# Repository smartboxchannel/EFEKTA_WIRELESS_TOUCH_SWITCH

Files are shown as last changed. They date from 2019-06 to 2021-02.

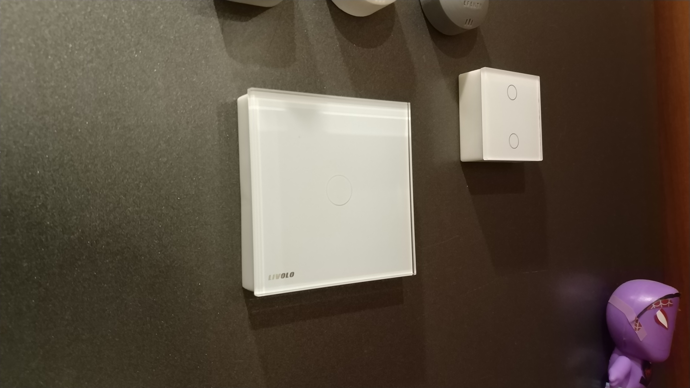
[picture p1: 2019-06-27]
IMAGES/IMG_20190627_012042.jpg

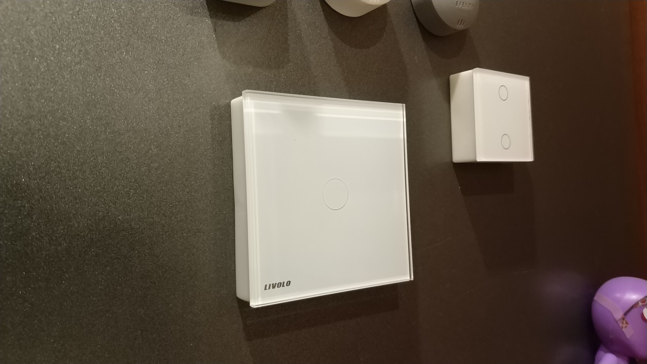
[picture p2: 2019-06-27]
IMAGES/IMG_20190627_012049.jpg

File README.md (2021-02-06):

Wireless Touch Switch sensor based on nRF52832 with fluorescent effect. Running on cr2450 battery (550mA).

Use the MySensors library

#### Don't donate to me, it doesn't work in this world: https://paypal.me/efektalab , just buy:

More info at http://efektalab.com/wts52

Contact: hello@efektalab.com

---

---

Components (see also BOM.CSV):

Luxury Crystal White Glass Touch Switch Panel 80mm*80mm - http://ali.ski/s-sSY

Luminous Tape Night Vision Glow - http://ali.ski/LCVzK

ANYCUBIC 405nm UV Resin For Photon 3D Printer - http://ali.ski/MQ5yO3

Head Micro Screws Round - http://ali.ski/Tqzrc

Super Strong Block Square Rare Earth Neodymium Magnets - http://ali.ski/Edmjy

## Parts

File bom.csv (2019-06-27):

Qty | Value | Device | Package | Parts | Description | MF | MPN | Aliexpress or Ebay link
2 | 100nF | 50v | +80-20% |  | SMD 0805 | C1, C4 | SMD ceramic capacitor 100nF | Y5V |  |  | http://ali.ski/nnISH
1 | 47uF | 6v3 | 10% |  | SMD 1812 | C2 | SMD ceramic capacitor 47uF | Y5V |  |  | http://ali.ski/B89nD8
1 | 10pF | 50v | +80-20% |  | SMD 0805 | C3 | SMD ceramic capacitor 47uF | Y5V (optional) |  |  | http://ali.ski/nnISH
2 | 10K | 5% |  | SMD 0805 | R1, R2 | SMD resistor 10K Ohm |  |  | http://ali.ski/x9ghl
1 | 100K | 5% |  | SMD 0805 | R3 | SMD resistor 100K Ohm |  |  | http://ali.ski/x9ghl
2 | 2K | 5% |  | SMD 0805 | R4, R6 | SMD resistor 2K Ohm |  |  | http://ali.ski/x9ghl
1 | 360 | 5% |  | SMD 0805 | R5 | SMD resistor 360 Ohm |  |  | http://ali.ski/x9ghl
2 | 1PS76SB10.115 |  | SOD-323 | D1, D2 | SMD Schottky Barrier Diode |  |  | http://ali.ski/5dTu7U
1 | 2x3P | 6pin | 1.27mm |  | SMT | J1 | Pin Header Female |  |  | http://ali.ski/tKqX1J
1 | RGB LED |  | SMD 0805 | RGBL1 | RGB LED |  |  | http://ali.ski/BPc4y
1 | YJ-17103 |  | SMT | U2 | nRF52832 Module |  |  | http://ali.ski/elwkT
2 | Button |  | SMT | U3, U4 | b4.5x4.5 |  |  | http://ali.ski/7eX0DK
1 | TTP223 |  | SOT-23-6L | U5 | 1 KEY TOUCH PAD DETECTOR IC |  |  | http://ali.ski/RrWnC
1 | HU-2450 N-1 |  | DIP | U6 | Battery Holder |  |  | https://ru.mouser.com/ProductDetail/Renata/HU2450N-1?qs=weLdYPLz6SNVHVWWurrMmw%3D%3D

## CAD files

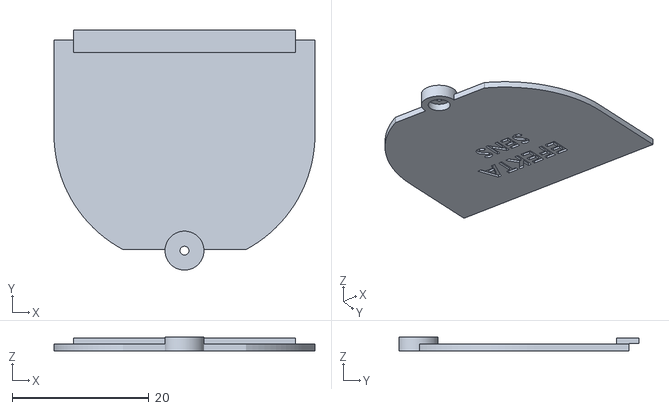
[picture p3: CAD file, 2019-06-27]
CASE/2.STL
38.2 x 35.2 x 2.00

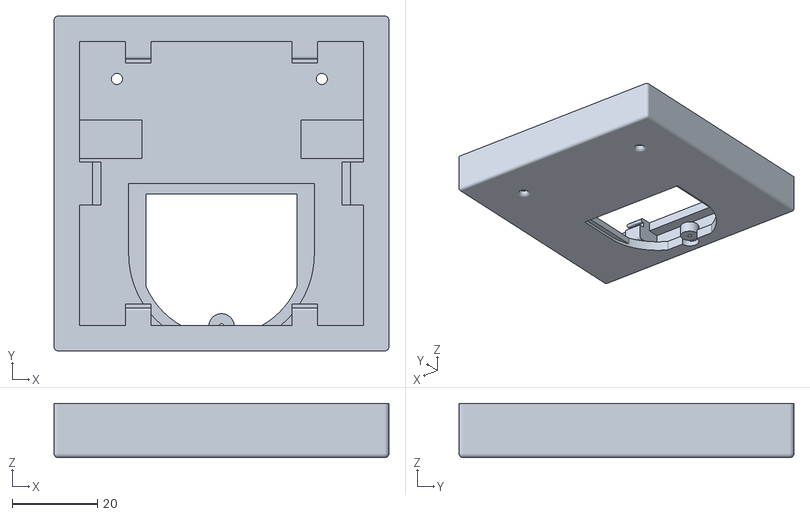
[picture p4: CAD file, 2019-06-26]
CASE/1.STL
78.5 x 78.5 x 12.7

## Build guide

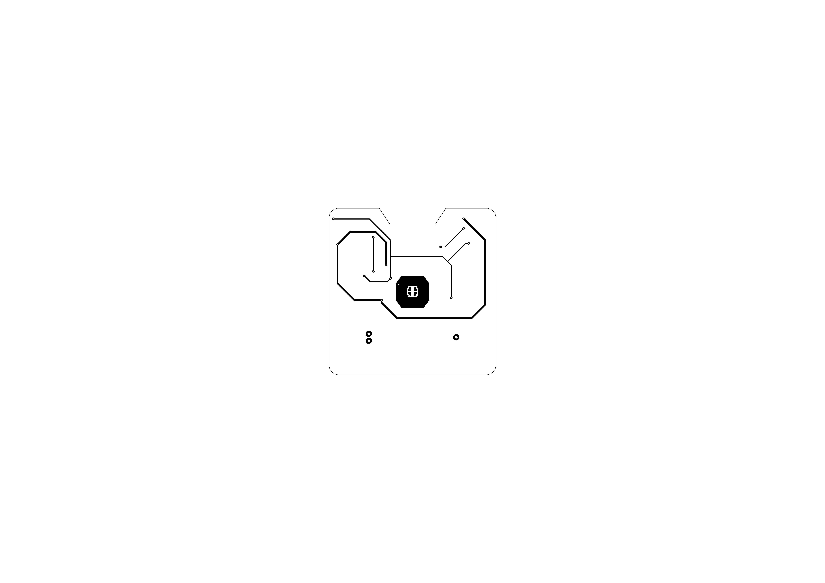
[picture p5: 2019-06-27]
GERBER_FILES/LUT_HAND_MADE/PRINT/1.jpg

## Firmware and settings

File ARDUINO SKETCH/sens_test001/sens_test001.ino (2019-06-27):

/**
  ТЕСТОВЫЙ СКЕТЧ СЕНСОРНОГО ВЫКЛЮЧАТЕЛЯ С ПРЕРЫВАНИЯМИ НА NRF_LPCOMP
*/
bool button_flag;
bool sens_flag;
bool send_flag;
bool detection;
bool nosleep;
byte timer;
unsigned long SLEEP_TIME = 21600000; //6 hours
unsigned long oldmillis;
unsigned long newmillis;
unsigned long interrupt_time;
unsigned long SLEEP_TIME_W;
uint16_t currentBatteryPercent;
uint16_t batteryVoltage = 0;
uint16_t battery_vcc_min = 2400;
uint16_t battery_vcc_max = 3000;

#define MY_RADIO_NRF5_ESB
//#define MY_PASSIVE_NODE
#define MY_NODE_ID 30
#define MY_PARENT_NODE_ID 0
#define MY_PARENT_NODE_IS_STATIC
#define MY_TRANSPORT_UPLINK_CHECK_DISABLED
#define IRT_PIN 3 //(PORT0,  gpio 5)
#include <MySensors.h>
// see https://www.mysensors.org/download/serial_api_20
#define SENS_CHILD_ID 0
#define CHILD_ID_VOLT 254
MyMessage sensMsg(SENS_CHILD_ID, V_VAR1);
//MyMessage voltMsg(CHILD_ID_VOLT, V_VOLTAGE);


void preHwInit() {
  sleep(2000);
  pinMode(RED_LED, OUTPUT);
  digitalWrite(RED_LED, HIGH);
  pinMode(GREEN_LED, OUTPUT);
  digitalWrite(GREEN_LED, HIGH);
  pinMode(BLUE_LED, OUTPUT);
  digitalWrite(BLUE_LED, HIGH);
  pinMode(MODE_PIN, INPUT);
  pinMode(SENS_PIN, INPUT);
}

void before()
{
  NRF_POWER->DCDCEN = 1;
  NRF_UART0->ENABLE = 0;
  sleep(1000);
  digitalWrite(BLUE_LED, LOW);
  sleep(150);
  digitalWrite(BLUE_LED, HIGH);
}

void presentation()  {
  sendSketchInfo("EFEKTA Sens 1CH Sensor", "1.1");
  present(SENS_CHILD_ID, S_CUSTOM, "SWITCH STATUS");
  //present(CHILD_ID_VOLT, S_MULTIMETER, "Battery");
}

void setup() {
  digitalWrite(BLUE_LED, LOW);
  sleep(100);
  digitalWrite(BLUE_LED, HIGH);
  sleep(200);
  digitalWrite(BLUE_LED, LOW);
  sleep(100);
  digitalWrite(BLUE_LED, HIGH);
  lpComp();
  detection = false;
  SLEEP_TIME_W = SLEEP_TIME;
  pinMode(31, OUTPUT);
  digitalWrite(31, HIGH);
  /*
    while (timer < 10) {
    timer++;
    digitalWrite(GREEN_LED, LOW);
    wait(5);
    digitalWrite(GREEN_LED, HIGH);
    wait(500);
    }
    timer = 0;
  */
  sleep(7000);
  while (timer < 3) {
    timer++;
    digitalWrite(GREEN_LED, LOW);
    sleep(15);
    digitalWrite(GREEN_LED, HIGH);
    sleep(85);
  }
  timer = 0;
  sleep(1000);
}

void loop() {

  if (detection) {
    if (digitalRead(MODE_PIN) == 1 && button_flag == 0 && digitalRead(SENS_PIN) == 0) {
      //back side button detection
      button_flag = 1;
      nosleep = 1;
    }
    if (digitalRead(MODE_PIN) == 1 && button_flag == 1 && digitalRead(SENS_PIN) == 0) {
      digitalWrite(RED_LED, LOW);
      wait(10);
      digitalWrite(RED_LED, HIGH);
      wait(50);
    }
    if (digitalRead(MODE_PIN) == 0 && button_flag == 1 && digitalRead(SENS_PIN) == 0) {
      nosleep = 0;
      button_flag = 0;
      digitalWrite(RED_LED, HIGH);
      lpComp_reset();
    }

    if (digitalRead(SENS_PIN) == 1 && sens_flag == 0 && digitalRead(MODE_PIN) == 0) {
      //sens detection
      sens_flag = 1;
      nosleep = 1;
      newmillis = millis();
      interrupt_time = newmillis - oldmillis;
      SLEEP_TIME_W = SLEEP_TIME_W - interrupt_time;
      if (send(sensMsg.set(detection))) {
        send_flag = 1;
      }
    }
    if (digitalRead(SENS_PIN) == 1 && sens_flag == 1 && digitalRead(MODE_PIN) == 0) {
      if (send_flag == 1) {
        while (timer < 10) {
          timer++;
          digitalWrite(GREEN_LED, LOW);
          wait(20);
          digitalWrite(GREEN_LED, HIGH);
          wait(30);
        }
        timer = 0;
      } else {
        while (timer < 10) {
          timer++;
          digitalWrite(RED_LED, LOW);
          wait(20);
          digitalWrite(RED_LED, HIGH);
          wait(30);
        }
        timer = 0;
      }
    }
    if (digitalRead(SENS_PIN) == 0 && sens_flag == 1 && digitalRead(MODE_PIN) == 0) {
      sens_flag = 0;
      nosleep = 0;
      send_flag = 0;
      digitalWrite(GREEN_LED, HIGH);
      sleep(500);
      lpComp_reset();
    }
    if (SLEEP_TIME_W < 60000) {
      SLEEP_TIME_W = SLEEP_TIME;
      sendBatteryStatus();
    }
  }
  else {
    //if (detection == -1) {
    SLEEP_TIME_W = SLEEP_TIME;
    sendBatteryStatus();
  }
  if (nosleep == 0) {
    oldmillis = millis();
    sleep(SLEEP_TIME_W);
  }
}

void sendBatteryStatus() {
  wait(20);
  batteryVoltage = hwCPUVoltage();
  wait(2);

  if (batteryVoltage > battery_vcc_max) {
    currentBatteryPercent = 100;
  }
  else if (batteryVoltage < battery_vcc_min) {
    currentBatteryPercent = 0;
  } else {
    currentBatteryPercent = (100 * (batteryVoltage - battery_vcc_min)) / (battery_vcc_max - battery_vcc_min);
  }

  sendBatteryLevel(currentBatteryPercent, 1);
  wait(2000, C_INTERNAL, I_BATTERY_LEVEL);
  //send(powerMsg.set(batteryVoltage), 1);
  //wait(2000, 1, V_VAR1);
}

void lpComp() {
  NRF_LPCOMP->PSEL = IRT_PIN;
  NRF_LPCOMP->ANADETECT = 1;
  NRF_LPCOMP->INTENSET = B0100;
  NRF_LPCOMP->ENABLE = 1;
  NRF_LPCOMP->TASKS_START = 1;
  NVIC_SetPriority(LPCOMP_IRQn, 15);
  NVIC_ClearPendingIRQ(LPCOMP_IRQn);
  NVIC_EnableIRQ(LPCOMP_IRQn);
}

void s_lpComp() {
  if ((NRF_LPCOMP->ENABLE) && (NRF_LPCOMP->EVENTS_READY)) {
    NRF_LPCOMP->INTENCLR = B0100;
  }
}

void r_lpComp() {
  NRF_LPCOMP->INTENSET = B0100;
}

#if __CORTEX_M == 0x04
#define NRF5_RESET_EVENT(event)                                                 \
  event = 0;                                                                   \
  (void)event
#else
#define NRF5_RESET_EVENT(event) event = 0
#endif

extern "C" {
  void LPCOMP_IRQHandler(void) {
    detection = true;
    NRF5_RESET_EVENT(NRF_LPCOMP->EVENTS_UP);
    NRF_LPCOMP->EVENTS_UP = 0;
    MY_HW_RTC->CC[0] = (MY_HW_RTC->COUNTER + 2);
  }
}

void lpComp_reset () {
  s_lpComp();
  detection = false;
  NRF_LPCOMP->EVENTS_UP = 0;
  r_lpComp();
}

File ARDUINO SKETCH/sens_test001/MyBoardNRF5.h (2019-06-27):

/*
  If you don't use an nRF5 board, you can ignore this file.

  This file was part of the "My Sensors nRF5 Boards" board repository
  available at https://github.com/mysensors/ArduinoBoards If you have
  questions, please refer the documentation at
  https://github.com/mysensors/ArduinoHwNRF5 first.

  This file is compatible with ArduinoHwNRF5 >= 0.2.0

  This file allows you to change the pins of internal hardware, like the
  serial port, SPI bus or Wire bus.

  All pins referenced here are mapped via the "g_ADigitalPinMap" Array
  defined in "MyBoardNRF5.cpp" to pins of the MCU.
  
  As an example, if you have at the third position in "g_ADigitalPinMap" the
  12, then all ports referenced in Arduino with 2 are mapped to P0.12. If you
  don't change the "g_ADigitalPinMap" Array, the Arduino pins 0..31 are
  translated to P0.00..P0..31.
   
  ###########################################################################
 
  This file is compatible with ArduinoHwNRF5 > 0.1.0
  Copyright (c) 2014-2015 Arduino LLC.  All right reserved.
  Copyright (c) 2016 Sandeep Mistry. All right reserved.
  Copyright (c) 2017 Sensnology AB. All right reserved.

  This library is free software; you can redistribute it and/or
  modify it under the terms of the GNU Lesser General Public
  License as published by the Free Software Foundation; either
  version 2.1 of the License, or (at your option) any later version.
  This library is distributed in the hope that it will be useful,
  but WITHOUT ANY WARRANTY; without even the implied warranty of
  MERCHANTABILITY or FITNESS FOR A PARTICULAR PURPOSE.
  See the GNU Lesser General Public License for more details.
  You should have received a copy of the GNU Lesser General Public
  License along with this library; if not, write to the Free Software
  Foundation, Inc., 51 Franklin St, Fifth Floor, Boston, MA  02110-1301  USA
*/

#ifndef _MYBOARDNRF5_H_
#define _MYBOARDNRF5_H_

#ifdef __cplusplus
extern "C"
{
#endif // __cplusplus

// Number of pins defined in PinDescription array
#define PINS_COUNT           (32u)
#define NUM_DIGITAL_PINS     (32u)
#define NUM_ANALOG_INPUTS    (8u)
#define NUM_ANALOG_OUTPUTS   (8u)

/* 
 *  LEDs
 *  
 *  This is optional
 *  
 *  With My Sensors, you can use
 *  hwPinMode() instead of pinMode()
 *  hwPinMode() allows to use advanced modes like OUTPUT_H0H1 to drive LEDs.
 *  https://github.com/mysensors/MySensors/blob/development/drivers/NRF5/nrf5_wiring_constants.h
 *
 */
#define PIN_LED1                (16)
#define PIN_LED2                (15)
#define PIN_LED3                (17)
#define RED_LED                 (PIN_LED1)
#define GREEN_LED              (PIN_LED2)
#define BLUE_LED                 (PIN_LED3)
#define INTERRUPT_PIN                 (5)
#define MODE_PIN                 (25)
#define SENS_PIN                 (27)


/* 
 * Analog ports
 *  
 * If you change g_APinDescription, replace PIN_AIN0 with
 * port numbers mapped by the g_APinDescription Array.
 * You can add PIN_AIN0 to the g_APinDescription Array if
 * you want provide analog ports MCU independed, you can add
 * PIN_AIN0..PIN_AIN7 to your custom g_APinDescription Array
 * defined in MyBoardNRF5.cpp
 */
static const uint8_t A0  = ADC_A0;
static const uint8_t A1  = ADC_A1;
static const uint8_t A2  = ADC_A2;
static const uint8_t A3  = ADC_A3;
static const uint8_t A4  = ADC_A4;
static const uint8_t A5  = ADC_A5;
static const uint8_t A6  = ADC_A6;
static const uint8_t A7  = ADC_A7;

/*
 * Serial interfaces
 * 
 * RX and TX are required.
 * If you have no serial port, use unused pins
 * CTS and RTS are optional.
 */
#define PIN_SERIAL_RX       (11)
#define PIN_SERIAL_TX       (12)


#ifdef __cplusplus
}
#endif

#endif
